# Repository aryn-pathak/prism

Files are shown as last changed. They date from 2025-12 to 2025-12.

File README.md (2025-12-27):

# The Prism Flight Controller
## An STM32F401CCU6 based flight controller integrating BMP388 barometer and ICM-42688-P gyroscopic sensor, measuring just 2.5 x 2.5cm. 

### Images:






NOTE: work in progress, full project is aiming to have custom Prism firmware and a full drone build.

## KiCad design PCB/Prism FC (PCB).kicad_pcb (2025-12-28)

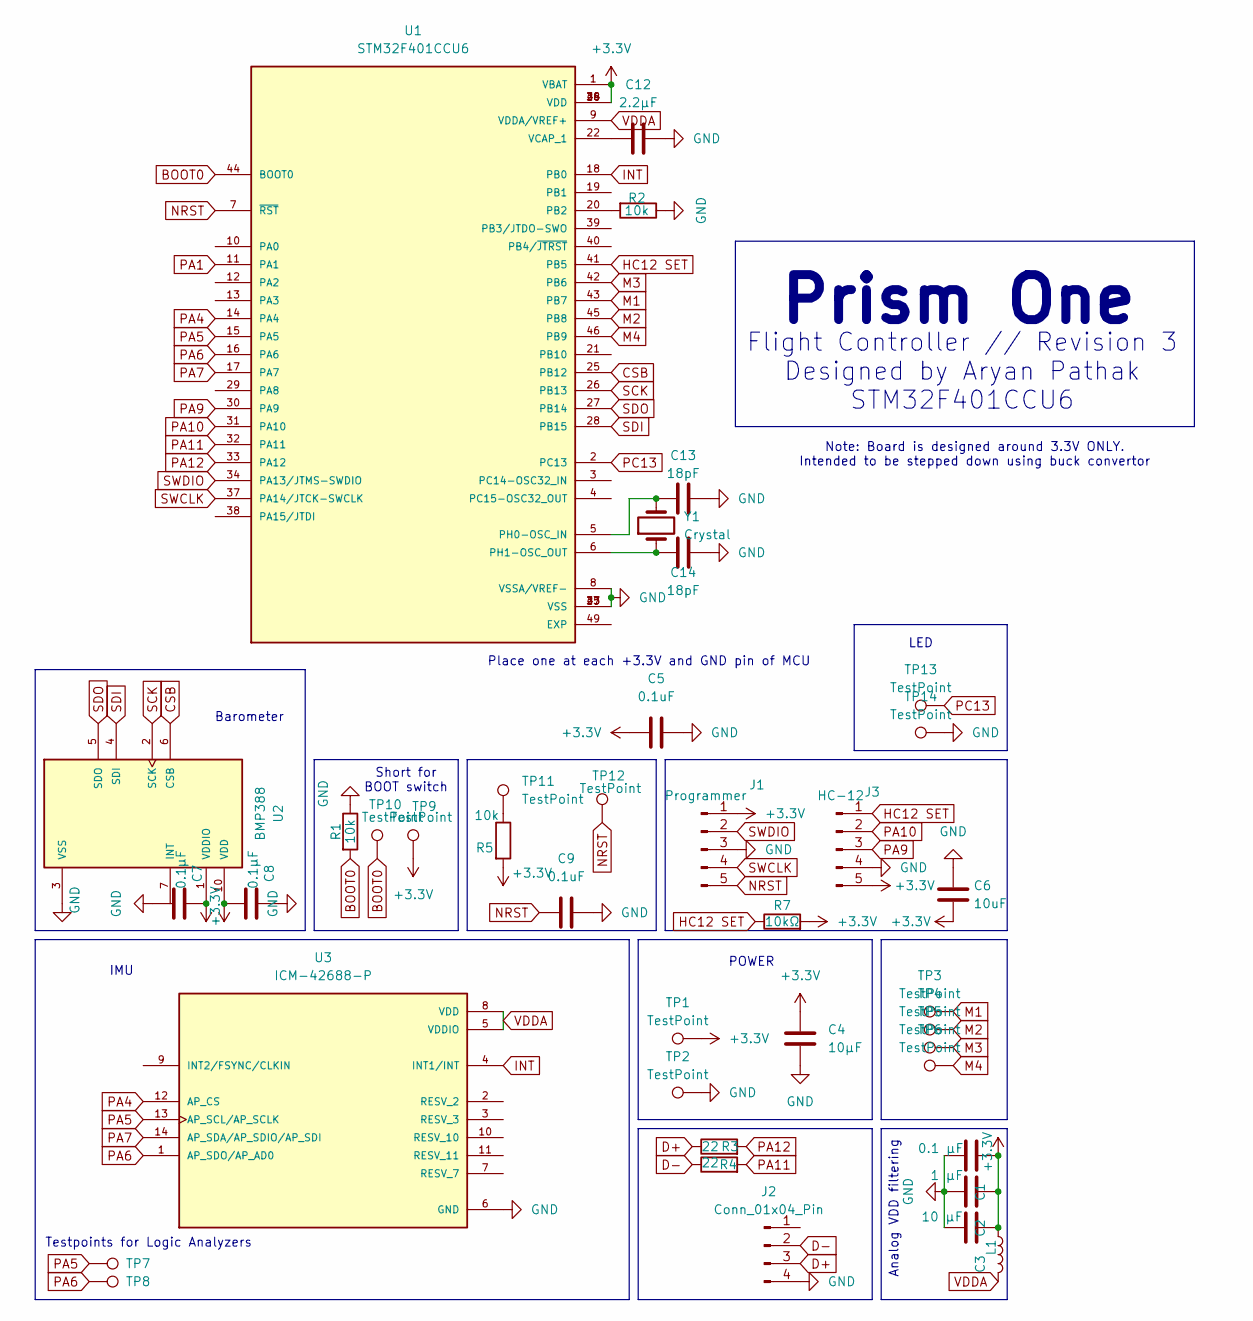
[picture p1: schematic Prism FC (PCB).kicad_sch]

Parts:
C1: 0.1 µF; C_0603_1608Metric
C2: 1 µF; C_0603_1608Metric
C3: 10 µF; C_0805_2012Metric
C4: 10µF; C_0805_2012Metric
C5, C9: 0.1uF; C_0603_1608Metric
C6: 10uF; C_0805_2012Metric
C7, C8: 0.1µF; C_0603_1608Metric
C12: 2.2µF; C_0805_2012Metric
C13, C14: 18pF; C_0603_1608Metric
J1: Programmer; PinHeader_1x05_P1.00mm_Vertical
J2: Conn_01x04_Pin; PinHeader_1x04_P1.00mm_Vertical
J3: HC-12; PinHeader_1x05_P1.00mm_Vertical
L1: L; R_0603_1608Metric
R1, R2, R5: 10k; R_0603_1608Metric
R3, R4: 22; R_0603_1608Metric
R7: 10kΩ; R_0603_1608Metric
TP1, TP2: TestPoint; TestPoint_THTPad_2.5x2.5mm_Drill1.2mm
TP3, TP4, TP5, TP6: TestPoint; TestPoint_Pad_1.5x1.5mm
TP7, TP8, TP9, TP10, TP11, TP12, TP13, TP14: TestPoint; TestPoint_Pad_D1.0mm
U1: STM32F401CCU6; PARTREV 11
U2: BMP388; 10LGA_2X2X0p75_BOS; PARTREV 1.1
U3: ICM-42688-P; PARTREV 1.2
Y1: Crystal; Crystal_SMD_Abracon_ABM7-2Pin_6.0x3.5mm

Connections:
+3.3V: C1.1, C2.1, C3.1, C4.1, C5.1, C6.2, C7.1, C8.2, J1.1, J3.5, L1.1, R5.2, R7.2, TP1.1, TP9.1, U1.1 (VBAT), U1.24 (VDD), U1.36 (VDD), U1.48 (VDD), U2.1 (VDDIO), U2.10 (VDD); also elsewhere on the board
BOOT0: R1.2, TP10.1, U1.44 (BOOT0)
CSB: U1.25 (PB12), U2.6 (CSB)
D+: J2.3, R3.1
D-: J2.2, R4.1
GND: C1.2, C2.2, C3.2, C4.2, C5.2, C6.1, C7.2, C8.1, C9.2, C12.2, C13.2, C14.2, J1.3, J2.4, J3.4, R1.1, R2.1, TP2.1, TP14.1, U1.8 (VSSA/VREF-), U1.23 (VSS), U1.35 (VSS), U1.47 (VSS), U1.49 (EXP), U2.3 (VSS), U2.8 (VSS), U2.9 (VSS), U3.6 (GND); also elsewhere on the board
HC12 SET: J3.1, R7.1, U1.41 (PB5)
INT: U1.18 (PB0), U3.4 (INT1/INT)
M1: TP3.1, U1.43 (PB7)
M2: TP4.1, U1.45 (PB8)
M3: TP5.1, U1.42 (PB6)
M4: TP6.1, U1.46 (PB9)
NRST: C9.1, J1.5, TP12.1, U1.7 (~RST)
unnamed: R5.1, TP11.1
unnamed: C13.1, U1.5 (PH0-OSC_IN), Y1.2
unnamed: C14.1, U1.6 (PH1-OSC_OUT), Y1.1
unnamed: C12.1, U1.22 (VCAP_1)
PA1: U1.11 (PA1)
PA4: U1.14 (PA4), U3.12 (AP_CS)
PA5: TP7.1, U1.15 (PA5), U3.13 (AP_SCL/AP_SCLK)
PA6: TP8.1, U1.16 (PA6), U3.1 (AP_SDO/AP_AD0)
PA7: U1.17 (PA7), U3.14 (AP_SDA/AP_SDIO/AP_SDI)
PA9: J3.3, U1.30 (PA9)
PA10: J3.2, U1.31 (PA10)
PA11: R4.2, U1.32 (PA11)
PA12: R3.2, U1.33 (PA12)
PB2: R2.2, U1.20 (PB2)
PC13: TP13.1, U1.2 (PC13)
SCK: U1.26 (PB13), U2.2 (SCK)
SDI: U1.28 (PB15), U2.4 (SDI)
SDO: U1.27 (PB14), U2.5 (SDO)
SWCLK: J1.4, U1.37 (PA14/JTCK-SWCLK)
SWDIO: J1.2, U1.34 (PA13/JTMS-SWDIO)
VDDA: L1.2, U1.9 (VDDA/VREF+), U3.5 (VDDIO), U3.8 (VDD)

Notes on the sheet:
Analog VDD filtering
POWER
Short for BOOT switch
Prism One
LED
Testpoints for Logic Analyzers
Flight Controller // Revision 3 Designed by Aryan Pathak STM32F401CCU6
Note: Board is designed around 3.3V ONLY. Intended to be stepped down using buck convertor
IMU
Place one at each +3.3V and GND pin of MCU
Barometer

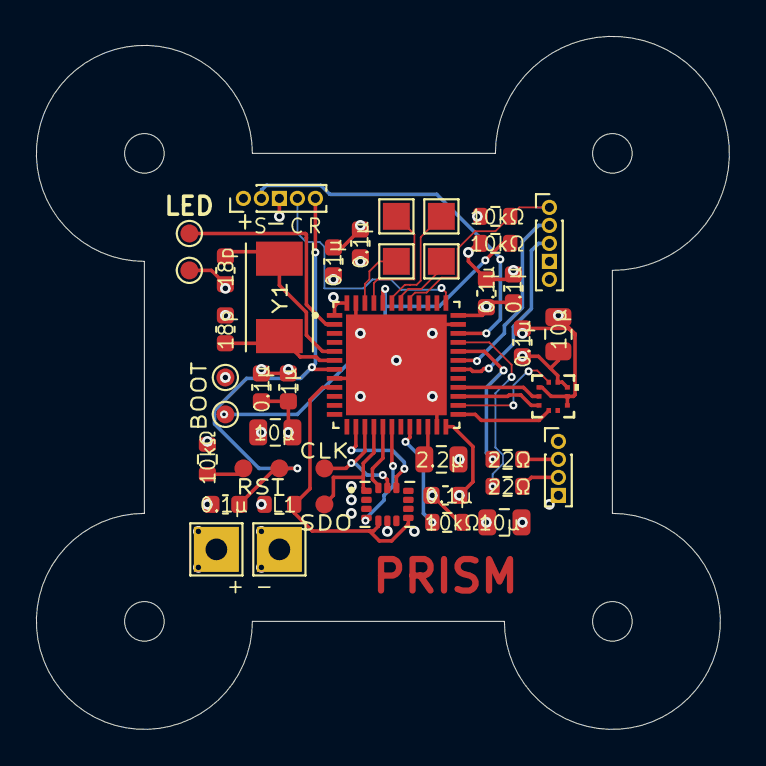
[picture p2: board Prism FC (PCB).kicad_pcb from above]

Board: 4 copper layers, 38.5 x 38.5 mm, 43 parts (0 on the bottom side), 33 nets.

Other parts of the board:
C5#2, C5#3, C5#4: 0.1uF; C_0603_1608Metric

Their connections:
+3.3V: C5#2.1, C5#3.1, C5#4.1; also elsewhere on the board
GND: C5#2.2, C5#3.2, C5#4.2; also elsewhere on the board

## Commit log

2025-12-26 gonna add new PCB and schematic files, cleaning up structure too
    [THRUST FC.kicad_pcb, THRUST FC.kicad_sch]
2025-12-26 removed old FC step model
    [THRUST FC.step]
2025-12-27 Rename THRUST assembly.zip to assembly.zip
2025-12-28 added PCB file
    [Prism FC (PCB).kicad_pcb]
